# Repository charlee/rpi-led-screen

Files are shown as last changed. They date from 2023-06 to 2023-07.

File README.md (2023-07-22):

LED Matrix screen with Raspberry Pi Pico
========================================

This is a screen made with 20 LED Matrix modules, each one with 8x8 LEDs, controlled by a Raspberry Pi Pico.
A Python script running on a computer captures the video frames from given YouTube video,
then send the pixelized frames to the Raspberry Pi Pico via USB.
Raspberry Pi Pico then displays the frames on the LED Matrix screen.

See the following video for demo.

Demo video (https://youtu.be/u_xRYg4IFwo)

## Hardware

See [hardware](hardware/) for details.

## Code for Raspberry Pi Pico

See [rp2040](rp2040/) for details.

## Code for Windows

See [win32](win32/) for details.

## 3D Models

See [cad](cad/) for details.

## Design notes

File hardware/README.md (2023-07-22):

Hardware of the LED screen
==========================

The famous video [Bad Apple!!](https://youtu.be/FtutLA63Cp8) has an aspect ratio of 4:3.
It must be pixelized before playing on the LED screen.
In order to maximize the resolution, the LED screen should be as close to 4:3 as possible.

After some calculation, I decided to use 20 LED Matrix modules, each one with 8x8 LEDs.
This makes a screen with 40x32 LEDs, which is very close to 4:3.

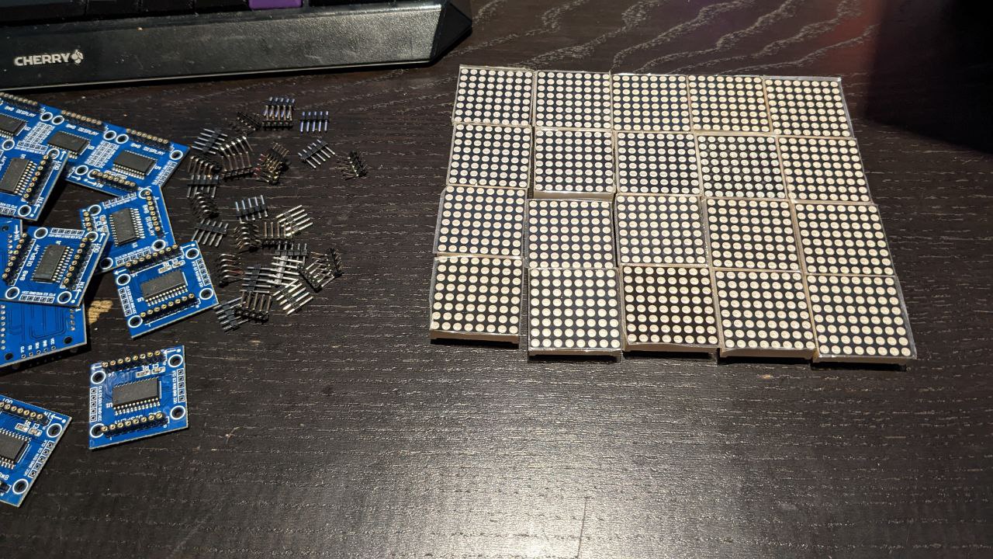
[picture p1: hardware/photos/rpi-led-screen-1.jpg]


A 3D printed frame is used to hold the LED Matrix modules together.

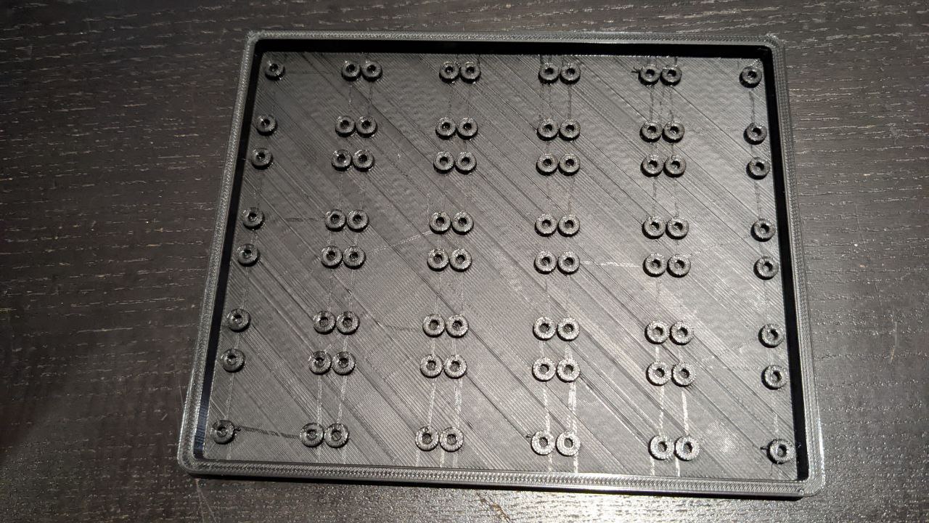
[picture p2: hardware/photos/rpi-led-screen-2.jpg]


Assemble the LED Matrix modules together.

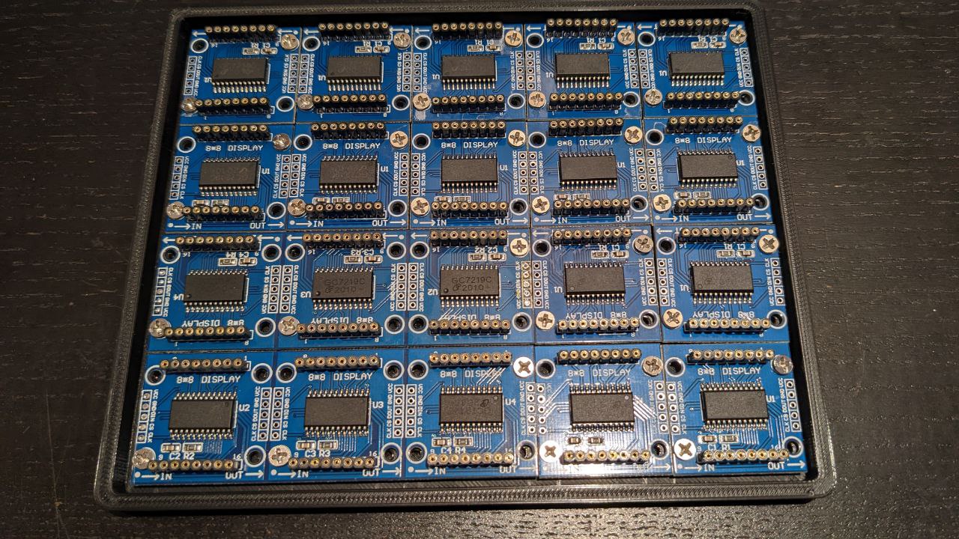
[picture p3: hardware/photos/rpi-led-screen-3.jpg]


The input will start from the bottom left corner, then go right, then go up, then go left, then go up, and so on - just like a snake. This is to minimize the length of the wires.
I didn't use the headers provided by the LED Matrix modules. Instead, I soldered the wires directly to the modules. Adjaent modules are soldered together, and the last module in each row is connected to the first module in the next row with wires.

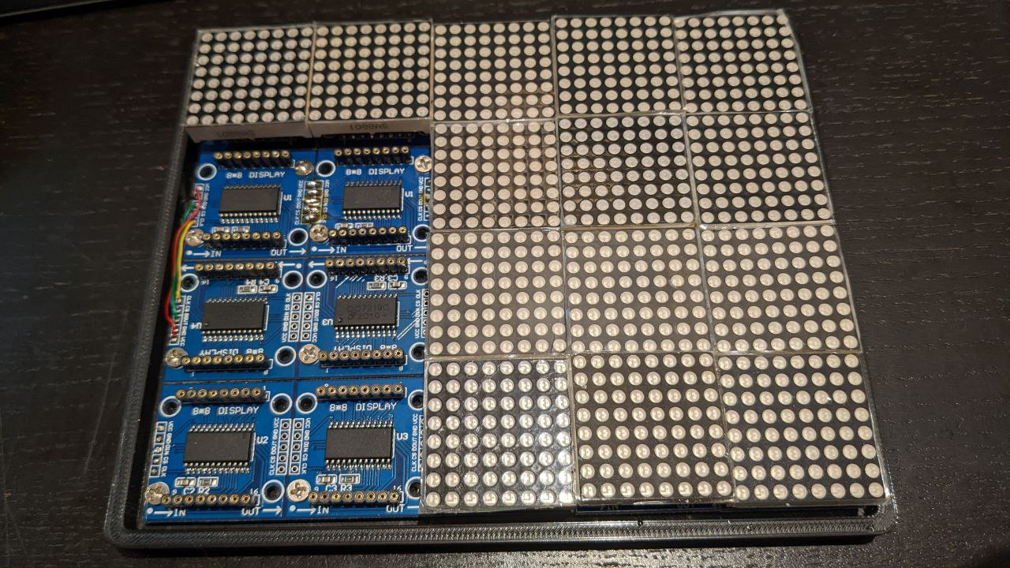
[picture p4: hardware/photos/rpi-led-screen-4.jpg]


I also need to consider where to put the Raspberry Pi Pico. To minimize the size of the screen,
I decided to put the Raspberry Pi Pico in the space between the LED Matrix modules and their PCBs, like this:

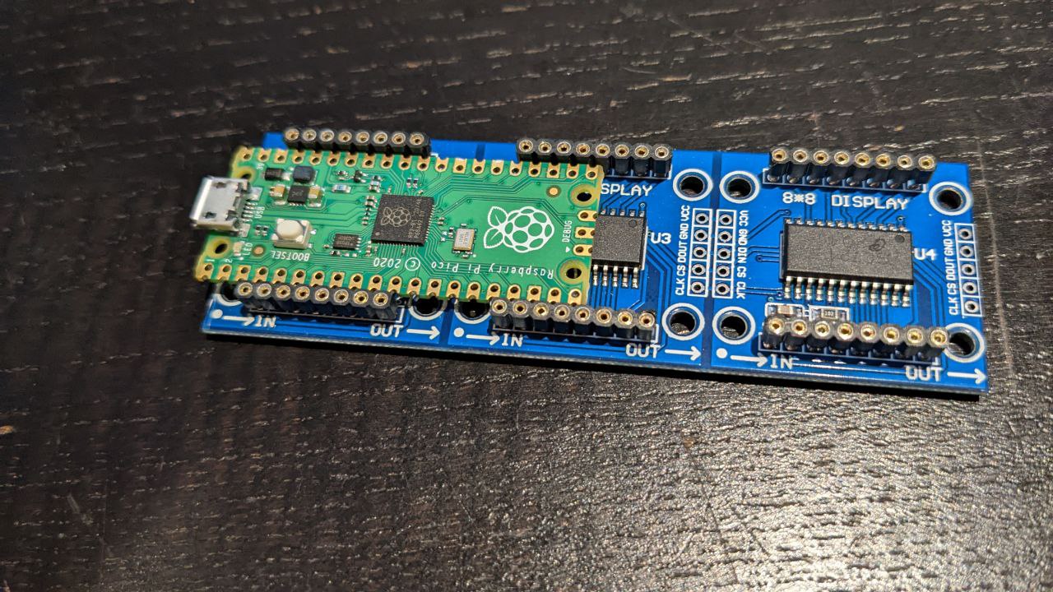
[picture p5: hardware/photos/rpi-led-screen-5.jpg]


A Raspberry Pi Pico without header fits perfectly in the space between the LED Matrix modules and their PCBs. To prevent short circuit, a 3D printed adapter is placed on the LED Matrix PCB. This piece is also used to hold the Raspberry Pi Pico in place.

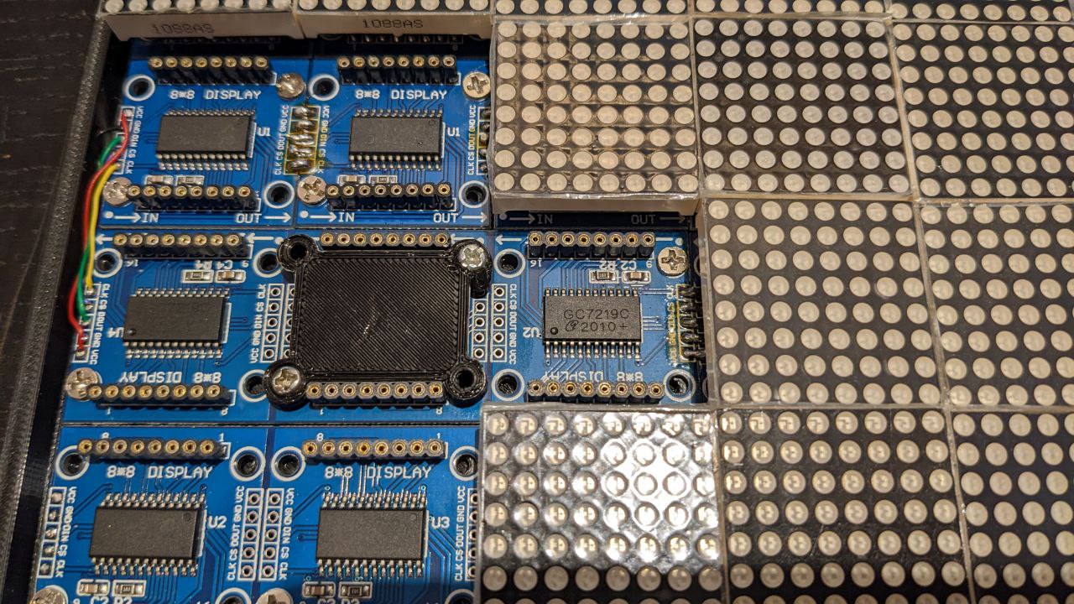
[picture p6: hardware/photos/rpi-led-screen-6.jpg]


Then put the Raspberry Pi Pico in place.

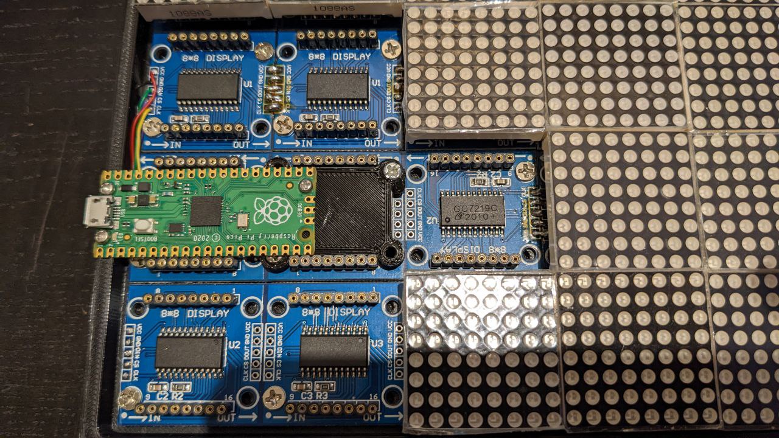
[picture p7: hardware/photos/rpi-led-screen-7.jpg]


The last step is to solder the wires to the Raspberry Pi Pico. I forgot to take a photo of this step, but it's pretty straightforward.

- LED Matrix VCC => Pico VBUS (pin 40)
- LED Matrix GND => Pico GND (pin 3)
- LED Matrix CLK => Pico GP2 (pin 4)
- LED Matrix DIN => Pico GP3 (pin 5)
- LED Matrix CS => Pico GP5 (pin 7)

Finally, print a frame for the screen, and glue a piece of acrylic to the frame.

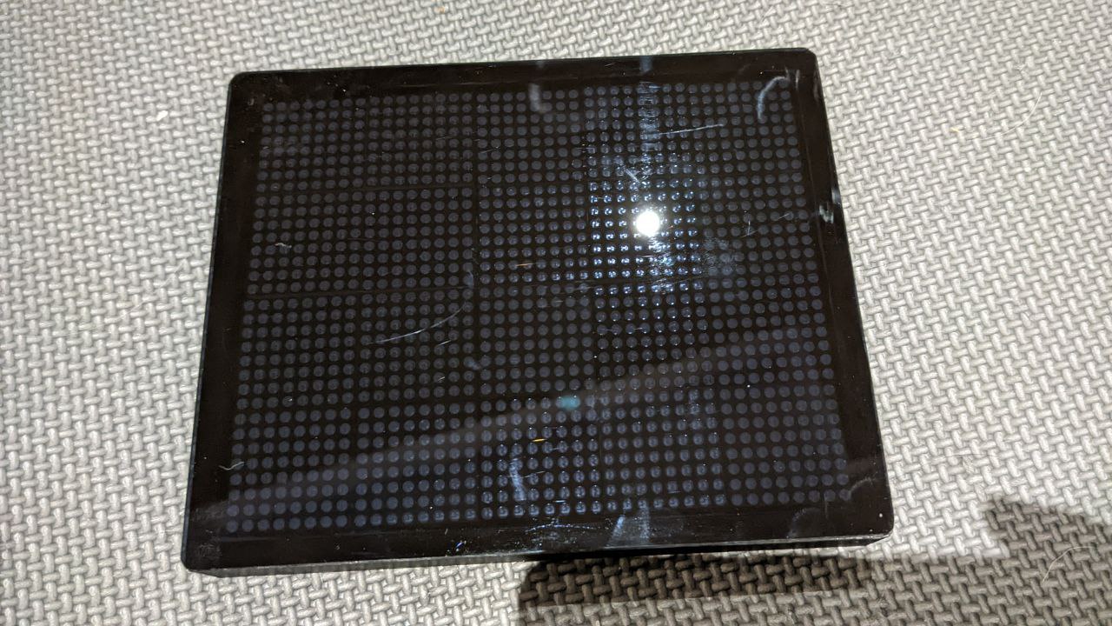
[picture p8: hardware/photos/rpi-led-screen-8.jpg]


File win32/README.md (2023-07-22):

RPi LED Screen Windows Player
==============================

This is the Windows player part for the RPi LED Screen.
Specified video file will be played and mapped to the screen.

`byteorder.py`: A helper module to convert the (x, y) cooridinate to the byte index and offset used by the LED matrix.

`play.py`: The main program.

`test_image.py`: A helper program to test the LED screen. It displays a letter on each LED module to test if the byte order is correct.

## Requirements

- Python 3.10 or later
- `opencv-python`: for converting the video frames to the LED screen format
- `dxcam`: for capturing the video frames from YouTube video
- `webview`: for creating a window to play the YouTube video
- `pyserial`: for sending data to the LED screen via USB

## Usage

```
# List available COM ports
python play.py -l

# Play the video  on the LED screen (replace COM3 with correct COM port)
python play.py -u https://www.youtube.com/watch?v=FtutLA63Cp8 -p COM3

# Play the video without sending it to the LED screen. Used for testing the video player
python play.py -u https://www.youtube.com/watch?v=FtutLA63Cp8

```

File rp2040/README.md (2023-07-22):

LED Screen controller on Raspberry Pi Pico
==========================================

This is a program running on Raspberry Pi Pico to control the LED Matrix screen.

## Prerequisites

- [CircuitPython](https://circuitpython.org/board/raspberry_pi_pico/) 8.1.0 or later (tested only on 8.1.0)
- [CircuitPython libraries](https://circuitpython.org/libraries).

This program requires the `adafruit_max7219` library.

`boot.py`

Enables the USB data port and disables the USB storage and USB midi.

`code.py`

The main program.

This program simply reads data from USB data port and sends it to the LED Matrix screen. All the data is sent as is, without any processing.
The Python script running on a computer (see `win32` folder) is responsible for sending the data in the correct format.

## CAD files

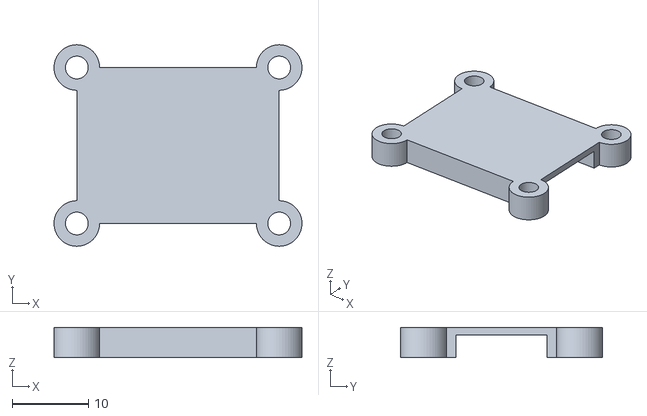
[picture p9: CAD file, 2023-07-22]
cad/PicoAdapter.stl
32.6 x 26.5 x 4.00

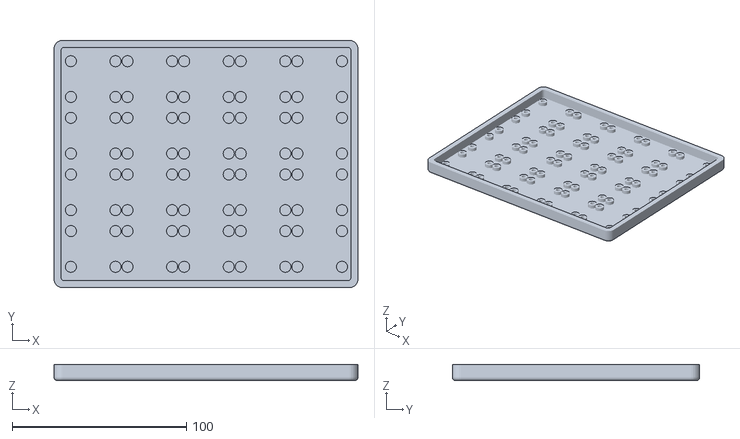
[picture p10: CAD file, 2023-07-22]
cad/baseplate.stl
174.5 x 142.0 x 9.40

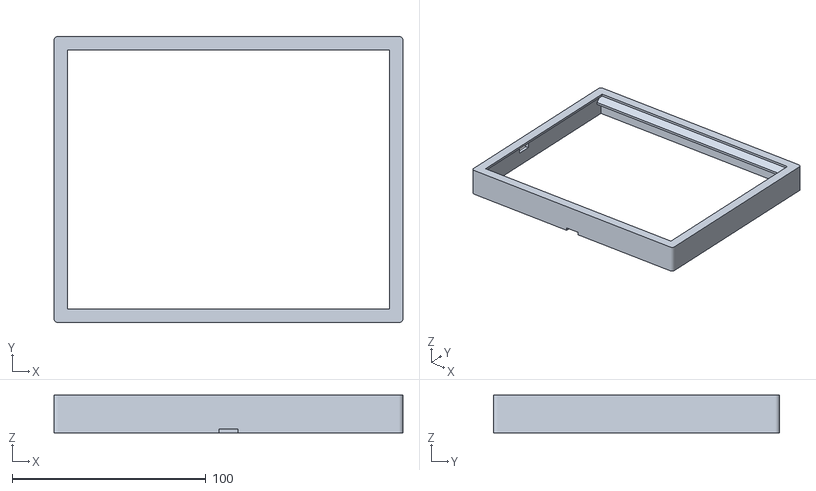
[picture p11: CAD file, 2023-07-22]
cad/topcover.stl
180.3 x 147.8 x 19.4

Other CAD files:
cad/Rpi-LED-Screen v6.f3d

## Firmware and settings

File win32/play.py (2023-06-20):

import time
import sys
import threading
import cv2
import webview
import dxcam
import argparse
from urllib.parse import urlparse, parse_qs
from byteorder import get_byte_index_offset
import serial.tools.list_ports


UI_TITLE_HEIGHT = 32

LEDSCREEN_W = 40
LEDSCREEN_H = 32


class YouTubePlayer:

    def __init__(self):
        self.window_x = 0
        self.window_y = 0
        self.window_w = 640
        self.window_h = 480
        self.video_loaded = False
        self.window_closed = False

        self.camera = None
        self.port = None
        self.serial = None
        
        self.lock = threading.Lock()
        
    def init_serial(self):
        '''
        Initialize serial port
        '''
        if self.port:
            self.serial = serial.Serial(self.port, 115200, timeout=1)
            print(f'Serial port initialized: {self.serial.name}')
        
    def send_bytes(self, bytes: bytearray):
        '''
        Send bytes to the serial port
        '''
        if self.serial:
            self.serial.write(bytes)


    def process_frame(self, frame):
        # gray scale
        frame = cv2.cvtColor(frame, cv2.COLOR_BGR2GRAY)
        
        # resize to the best w, h
        frame = cv2.resize(frame, (LEDSCREEN_W, LEDSCREEN_H))

        # threshold
        _, frame = cv2.threshold(frame, 127, 255, cv2.THRESH_BINARY)
        
        return frame
    
    def send_frame_to_ledscreen(self, frame):
        '''
        Send frame to LED screen
        '''
        # convert to bytes
        size = LEDSCREEN_W * LEDSCREEN_H // 8
        bytes = bytearray(size)

        for y in range(LEDSCREEN_H):
            for x in range(0, LEDSCREEN_W):
                if frame[y][x] == 0:
                    bit = 0
                else:
                    bit = 1
                index, offset = get_byte_index_offset(x, y)
                bytes[index] |= bit << offset
        
        self.send_bytes(bytes)

    
    def restart_capturing(self):
        '''
        Restarts capturing with the new window region.
        '''
        if not self.camera:
            return
        
        # since this func may be called in the event, need to use lock to prevent camera being read
        self.lock.acquire()

        if self.camera.is_capturing:
            self.camera.stop()

        region = (self.window_x, self.window_y + UI_TITLE_HEIGHT, self.window_x + self.window_w, self.window_y + self.window_h + UI_TITLE_HEIGHT)
        self.camera.start(region=region, target_fps=30)

        self.lock.release()


    def handle_video(self, window):
        
        self.init_serial()
        self.camera = dxcam.create(output_color="BGR")
        
        # wait for window to be moved
        while not self.video_loaded:
            time.sleep(0.1)
        
        
        # start a cv2 window to show the captured preview
        cv2.namedWindow('preview', cv2.WINDOW_NORMAL)
        cv2.resizeWindow('preview', self.window_w, self.window_h)
        
        # start capturing
        # acquire lock to prevent camera being restarted
        self.restart_capturing()
        while not self.window_closed:

            # capture one frame
            self.lock.acquire()
            frame = self.camera.get_latest_frame()
            if frame is None:
                continue
            self.lock.release()
            
            # process frame
            frame = self.process_frame(frame)
            
            # send to screen
            self.send_frame_to_ledscreen(frame)

            # show preview
            cv2.imshow('preview', frame)
            cv2.waitKey(1)
            
        self.camera.stop()
        del self.camera

        cv2.destroyAllWindows()
        
        if self.serial:
            self.serial.close()


    def play(self):
        # parse video url. Specify -p for com ports, specify -l to list available com ports
        parser = argparse.ArgumentParser()
        parser.add_argument('-u', '--url', help='YouTube video URL', required=False)
        parser.add_argument('-p', '--port', help='COM port', required=False)
        parser.add_argument('-l', '--list', action='store_true', help='List available COM ports', required=False)
        args = parser.parse_args()
        
        if args.list:
            ports = serial.tools.list_ports.comports()
            for port in ports:
                print(f'{port.device}: {port.description}')
            exit(0)
            
        if not args.url:
            # show error message to STDERR
            print('Please specify YouTube video URL', file=sys.stderr)
            parser.print_help()
            exit(0)
            
        if not args.port:
            print('COM port not specified, preview only', file=sys.stderr)
            
            
        # verify port name
        if args.port:
            ports = serial.tools.list_ports.comports()
            port_names = [port.device for port in ports]
            if args.port not in port_names:
                print(f'Invalid COM port: {args.port}', file=sys.stderr)
                exit(0)

            self.port = args.port

        url = args.url
        
        # parse video id using urlparse
        url_data = urlparse(url)
        query = parse_qs(url_data.query)
        video_id = query["v"][0]

        # generate embed url
        url = 'https://www.youtube.com/embed/{}?autoplay=1&rel=0'.format(video_id)
        
        # generate a webpage that contains the above url
        html = '''
<html>
<body style="margin:0px;padding:0px;overflow:hidden">
  <iframe src="{}" frameborder="0" allowfullscreen style="overflow:hidden;height:100%;width:100%" height="100%" width="100%"></iframe>
  </div>
</body>
</html>
'''.format(url)

        # event callbacks
        def on_loaded():
            self.video_loaded = True

        def on_moved(x, y):
            self.window_x = x
            self.window_y = y
            self.restart_capturing()
            
        def on_closed():
            self.window_closed = True
            print('Window closed')
            
        def handle_play(window):
            self.handle_video(window)

        # create window
        window = webview.create_window('YouTube Player', html=html, width=640, height=480 + UI_TITLE_HEIGHT, resizable=False, fullscreen=False)
        window.events.loaded += on_loaded
        window.events.moved += on_moved
        window.events.closed += on_closed
        webview.start(handle_play, window)


if __name__ == '__main__':
    player = YouTubePlayer()
    player.play()

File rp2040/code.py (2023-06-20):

import usb_cdc
import time
import board
import busio
import digitalio
from adafruit_max7219.matrices import CustomMatrix

LED_SCREEN_WIDTH = 40
LED_SCREEN_HEIGHT = 32

serial = usb_cdc.data
spi = busio.SPI(board.GP2, MOSI=board.GP3)
screen = CustomMatrix(
    width=LED_SCREEN_WIDTH * LED_SCREEN_HEIGHT // 8,
    height=8,
    spi=spi,
    cs=digitalio.DigitalInOut(board.GP5),
)

def show_ready():
    screen.fill(0)
    screen.text('READY', 5, 0)
    screen.show()


data_size = LED_SCREEN_WIDTH * LED_SCREEN_HEIGHT // 8
data = bytearray([0] * data_size)
p = 0

print('Started, waiting for data')
show_ready()

frame_count = 0
ts_start = time.monotonic()
last_ts = 0

while True:
    if serial.in_waiting > 0:
        buf = serial.read(data_size)
        screen._buffer = buf
        screen.show()
        frame_count += 1
        ts = time.monotonic()
        
        # print fps every second
        if ts - last_ts >= 1:
            print(f'fps = {frame_count / (ts - ts_start)}')
            last_ts = ts
    
    else:
        time.sleep(0.01)
    

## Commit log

2023-06-19 added video capture and frame processing
2023-06-19 send data to led screen
2023-07-22 added readme, caf files
    [PicoAdapter.stl, Rpi-LED-Screen v6.f3d, baseplate.stl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]
